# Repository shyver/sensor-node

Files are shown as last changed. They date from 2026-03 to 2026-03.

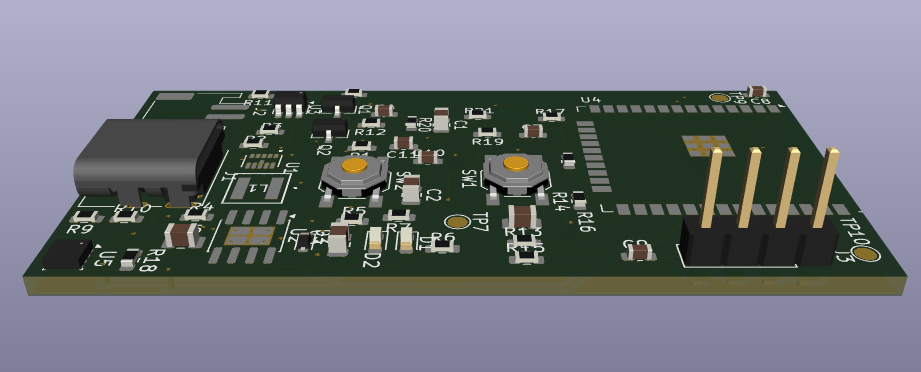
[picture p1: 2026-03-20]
media/pcb_3d_angle.png

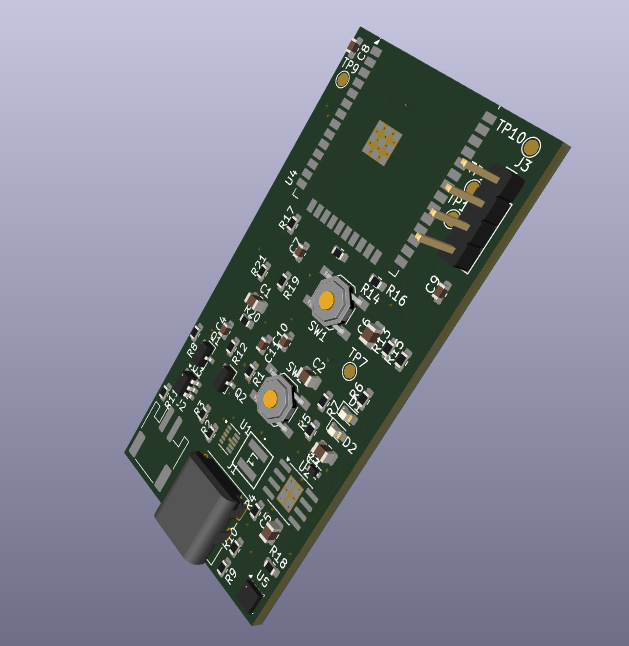
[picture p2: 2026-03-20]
media/pcb_3d_iso.png

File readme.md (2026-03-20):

# Battery-Powered ESP32 Environmental Sensor Node

## Overview

This project is a compact, battery-powered environmental monitoring device built around the ESP32. It is designed to measure temperature, humidity, and atmospheric pressure, and transmit data wirelessly over Wi-Fi.

The system integrates power management, battery charging, sensing, and communication into a single PCB, making it suitable for IoT applications and embedded product prototyping.

---

## Features

* ESP32-based Wi-Fi connectivity
* Environmental sensing (temperature, humidity, pressure)
* Battery-powered operation (Li-Po)
* USB-C power input and charging
* Integrated battery protection
* Low-power design (deep sleep capable)
* UART interface for programming and debugging

---

## Hardware Architecture

The system is composed of the following main subsystems:

### Power Subsystem

* USB-C 5V input
* Li-Po battery charging IC
* Battery protection circuit
* 3.3V regulation stage
* Bulk and decoupling capacitors

### Processing Unit

* ESP32-WROOM-32 module
* Boot configuration and reset circuitry
* UART programming interface

### Sensor Subsystem

* BME280 environmental sensor (I2C interface)
* Pull-up resistors for I2C communication

---

## Block Diagram

```
USB-C → Charger → Battery → Regulator → ESP32 → Sensor (I2C)
```

---

## Design Highlights

* Modular schematic organization (power / MCU / sensor)
* Proper decoupling and power distribution
* ESP32 antenna keep-out respected
* I2C bus design with pull-up resistors
* Battery protection and safe charging design

---

## Key Engineering Decisions

* **ESP32 Module Selection**
  Used a pre-certified ESP32 module to simplify RF design and ensure reliable Wi-Fi performance.

* **Battery-Powered Architecture**
  Designed around a single-cell Li-Po battery for portability and real-world IoT use cases.

* **Power Regulation Strategy**
  Implemented a regulated 3.3V rail to ensure stable operation during ESP32 current spikes.

* **USB-C Power-Only Configuration**
  USB-C connector used strictly for power input, avoiding unnecessary USB data complexity.

* **I2C Sensor Interface**
  Selected a digital sensor with I2C to minimize pin usage and simplify routing.

---

## PCB Design

* 2-layer PCB
* Ground plane for signal integrity
* Compact component placement
* Standard SMD components (0603 passives)
* Connector placement optimized for usability

---

## Files Included

### Design Files

* Schematic files
* PCB layout files

### Manufacturing Files

* Gerbers
* Drill files
* Bill of Materials (BOM)
* Pick-and-place files

### Documentation

* Block diagram
* Rendered board images

---

## Applications

* IoT environmental monitoring
* Smart home systems
* Remote sensing nodes
* Battery-powered embedded systems

---

## Future Improvements

* Power path optimization (load sharing / advanced charger IC)
* Lower power consumption tuning
* OTA firmware update support
* Enclosure design integration
* Additional sensor support

---

## Author

Hardware design and layout by Abdelwahed Eloued

---

## License

This project is open-source and available under the MIT License.

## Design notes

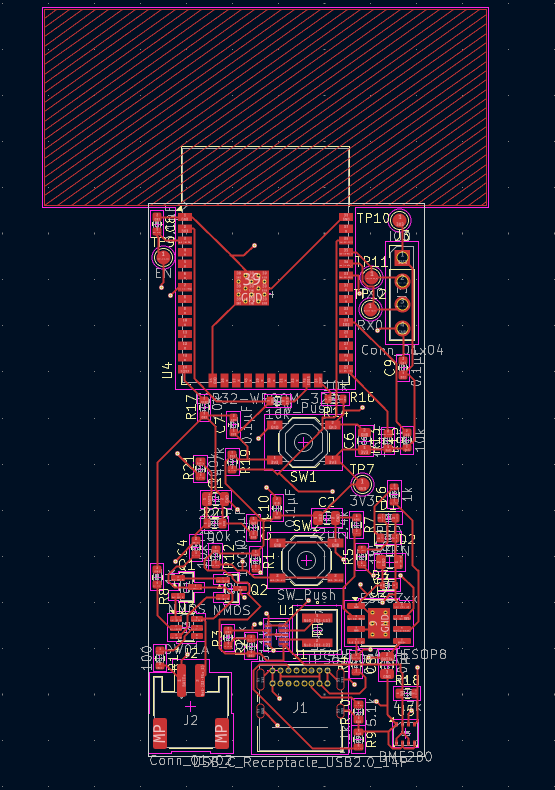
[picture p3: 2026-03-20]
media/pcb_front.png

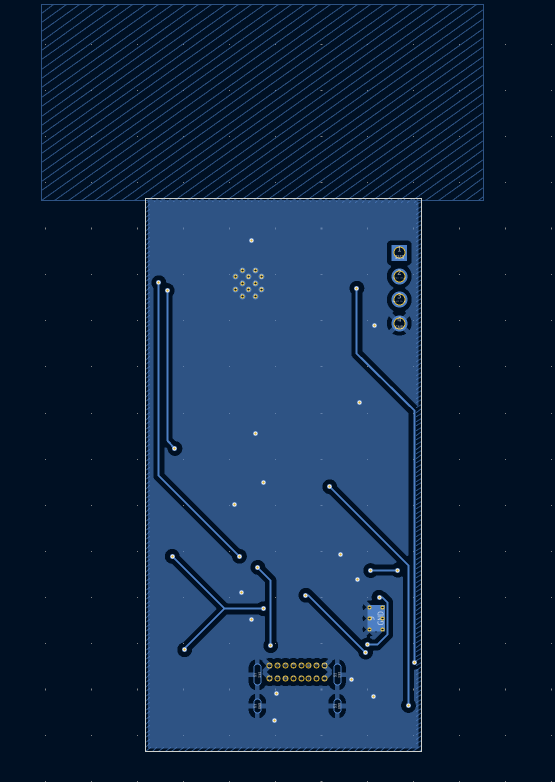
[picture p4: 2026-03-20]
media/pcb_back.png

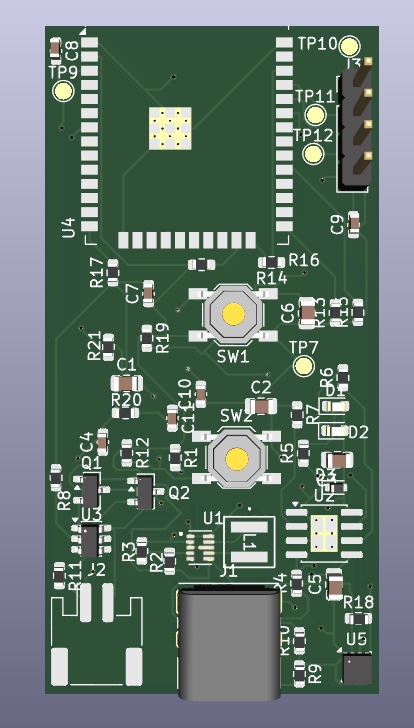
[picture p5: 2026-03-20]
media/pcb_3d_ortho.png

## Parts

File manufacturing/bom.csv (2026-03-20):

Reference | Qty | Value | DNP | Exclude from BOM | Exclude from Board | Footprint | Datasheet
C1,C2 | 2 | 22µF |  |  |  | Capacitor_SMD:C_0805_2012Metric | ~
C3,C5,C6 | 3 | 10µF |  |  |  | Capacitor_SMD:C_0805_2012Metric | ~
C4,C7,C8,C9,C10,C11 | 6 | 0.1µF |  |  |  | Capacitor_SMD:C_0603_1608Metric | ~
D1 | 1 | RED |  |  |  | LED_SMD:LED_0603_1608Metric | ~
D2 | 1 | GREEN |  |  |  | LED_SMD:LED_0603_1608Metric | ~
D3 | 1 | ESD5Zxx |  |  |  | Diode_SMD:D_SOD-523 | https://www.onsemi.com/pdf/datasheet/esd5z2.5t1-d.pdf
J1 | 1 | USB_C_Receptacle_USB2.0_14P |  |  |  | Connector_USB:USB_C_Receptacle_GCT_USB4085 | https://www.usb.org/sites/default/files/documents/usb_type-c.zip
J2 | 1 | Conn_01x02 |  |  |  | Connector_JST:JST_PH_S2B-PH-SM4-TB_1x02-1MP_P2.00mm_Horizontal | ~
J3 | 1 | Conn_01x04 |  |  |  | Connector_PinHeader_2.54mm:PinHeader_1x04_P2.54mm_Vertical | ~
L1 | 1 | 470nH |  |  |  | ul_XFL4015-471MEC:IND_XFL4015_COC-M | ~
Q1,Q2 | 2 | NMOS |  |  |  | Package_TO_SOT_SMD:SOT-23 | https://ngspice.sourceforge.io/docs/ngspice-html-manual/manual.xhtml#cha_MOSFETs
R1,R20,R21 | 3 | 100k |  |  |  | Resistor_SMD:R_0603_1608Metric | ~
R2 | 1 | 511k |  |  |  | Resistor_SMD:R_0603_1608Metric | ~
R3 | 1 | 91k |  |  |  | Resistor_SMD:R_0603_1608Metric | ~
R4 | 1 | 0.4 |  |  |  | Resistor_SMD:R_0603_1608Metric | ~
R5,R6,R8 | 3 | 1k |  |  |  | Resistor_SMD:R_0603_1608Metric | ~
R7 | 1 | 2.4k |  |  |  | Resistor_SMD:R_0603_1608Metric | ~
R9,R10 | 2 | 5.1k |  |  |  | Resistor_SMD:R_0603_1608Metric | ~
R11 | 1 | 100 |  |  |  | Resistor_SMD:R_0603_1608Metric | ~
R12,R13,R14,R15,R16,R17 | 6 | 10k |  |  |  | Resistor_SMD:R_0603_1608Metric | ~
R18,R19 | 2 | 4.7k |  |  |  | Resistor_SMD:R_0603_1608Metric | ~
SW1,SW2 | 2 | SW_Push |  |  |  | Button_Switch_SMD:SW_SPST_TL3342 | ~
TP7 | 1 | 3V3 |  |  |  | TestPoint:TestPoint_Pad_D1.5mm | ~
TP9 | 1 | EN |  |  |  | TestPoint:TestPoint_Pad_D1.5mm | ~
TP10 | 1 | IO0 |  |  |  | TestPoint:TestPoint_Pad_D1.5mm | ~
TP11 | 1 | TX0 |  |  |  | TestPoint:TestPoint_Pad_D1.5mm | ~
TP12 | 1 | RX0 |  |  |  | TestPoint:TestPoint_Pad_D1.5mm | ~
U1 | 1 | TPS63802DLAR |  |  |  | TPS63802DLAR:VREG_TPS63802DLAR
U2 | 1 | TP4056-42-ESOP8 |  |  |  | Package_SO:SOIC-8-1EP_3.9x4.9mm_P1.27mm_EP2.41x3.3mm_ThermalVias | https://www.lcsc.com/datasheet/lcsc_datasheet_2410121619_TOPPOWER-Nanjing-Extension-Microelectronics-TP4056-42-ESOP8_C16581.pdf
U3 | 1 | DW01A |  |  |  | Package_TO_SOT_SMD:SOT-23-6 | https://hmsemi.com/downfile/DW01A.PDF
U4 | 1 | ESP32-WROOM-32E |  |  |  | RF_Module:ESP32-WROOM-32D | https://www.espressif.com/sites/default/files/documentation/esp32-wroom-32e_esp32-wroom-32ue_datasheet_en.pdf
U5 | 1 | BME280 |  |  |  | Package_LGA:Bosch_LGA-8_2.5x2.5mm_P0.65mm_ClockwisePinNumbering | https://www.bosch-sensortec.com/media/boschsensortec/downloads/datasheets/bst-bme280-ds002.pdf

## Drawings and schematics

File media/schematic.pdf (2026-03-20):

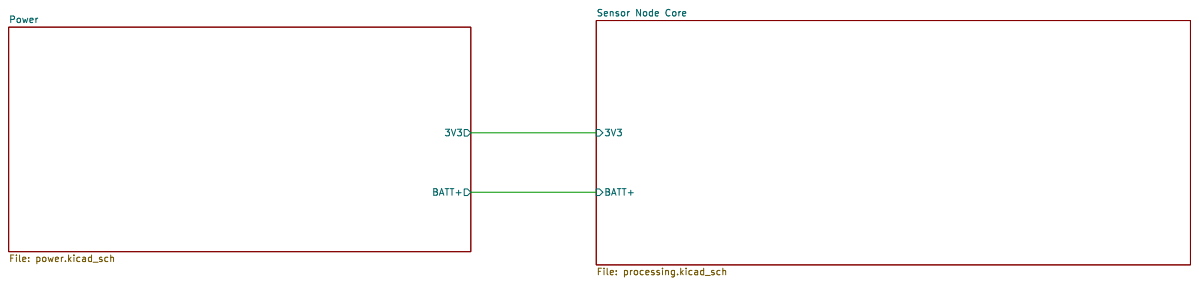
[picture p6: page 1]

3V3 BATT+ Power File: power.kicad_sch

3V3 BATT+ Sensor Node Core File: processing.kicad_sch

Id: 1/3 Title: File: sensor_node_kicad.kicad_sch Sheet: /

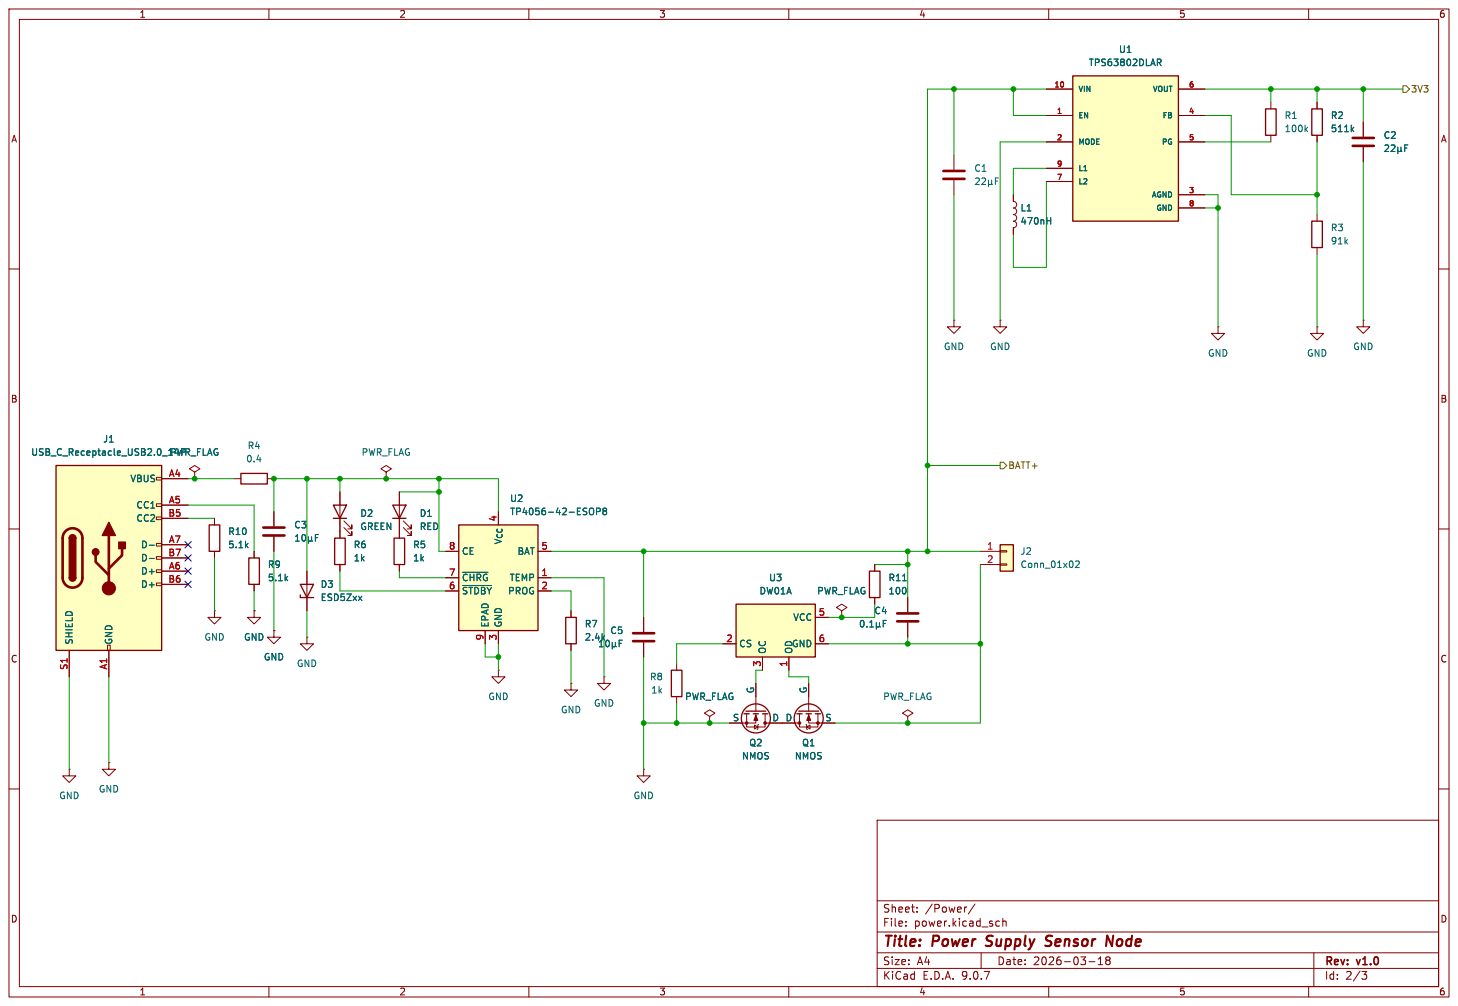
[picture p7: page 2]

3 BAT 5 TEMP 1 PROG 2 U2 TP4056-42-ESOP8 GND

File: power.kicad_sch Sheet: /Power/
Id: 2/3 Title: Power Supply Sensor Node

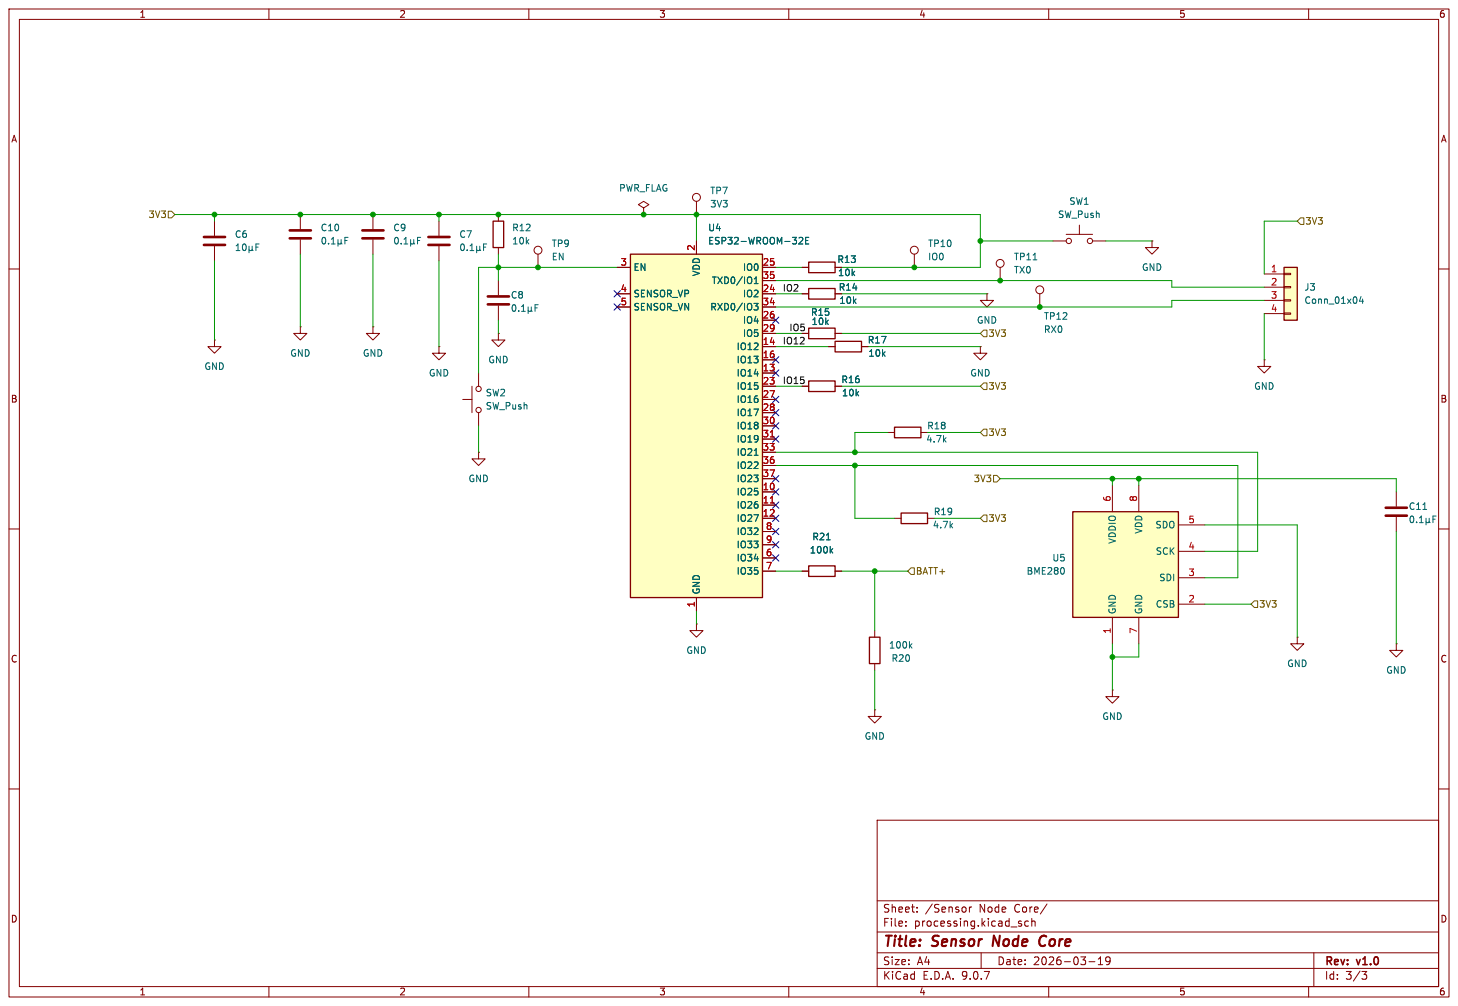
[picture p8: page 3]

7 SDO 5 SCK 4 SDI 3 CSB 2 U5 BME280 C7

Id: 3/3 Title: Sensor Node Core

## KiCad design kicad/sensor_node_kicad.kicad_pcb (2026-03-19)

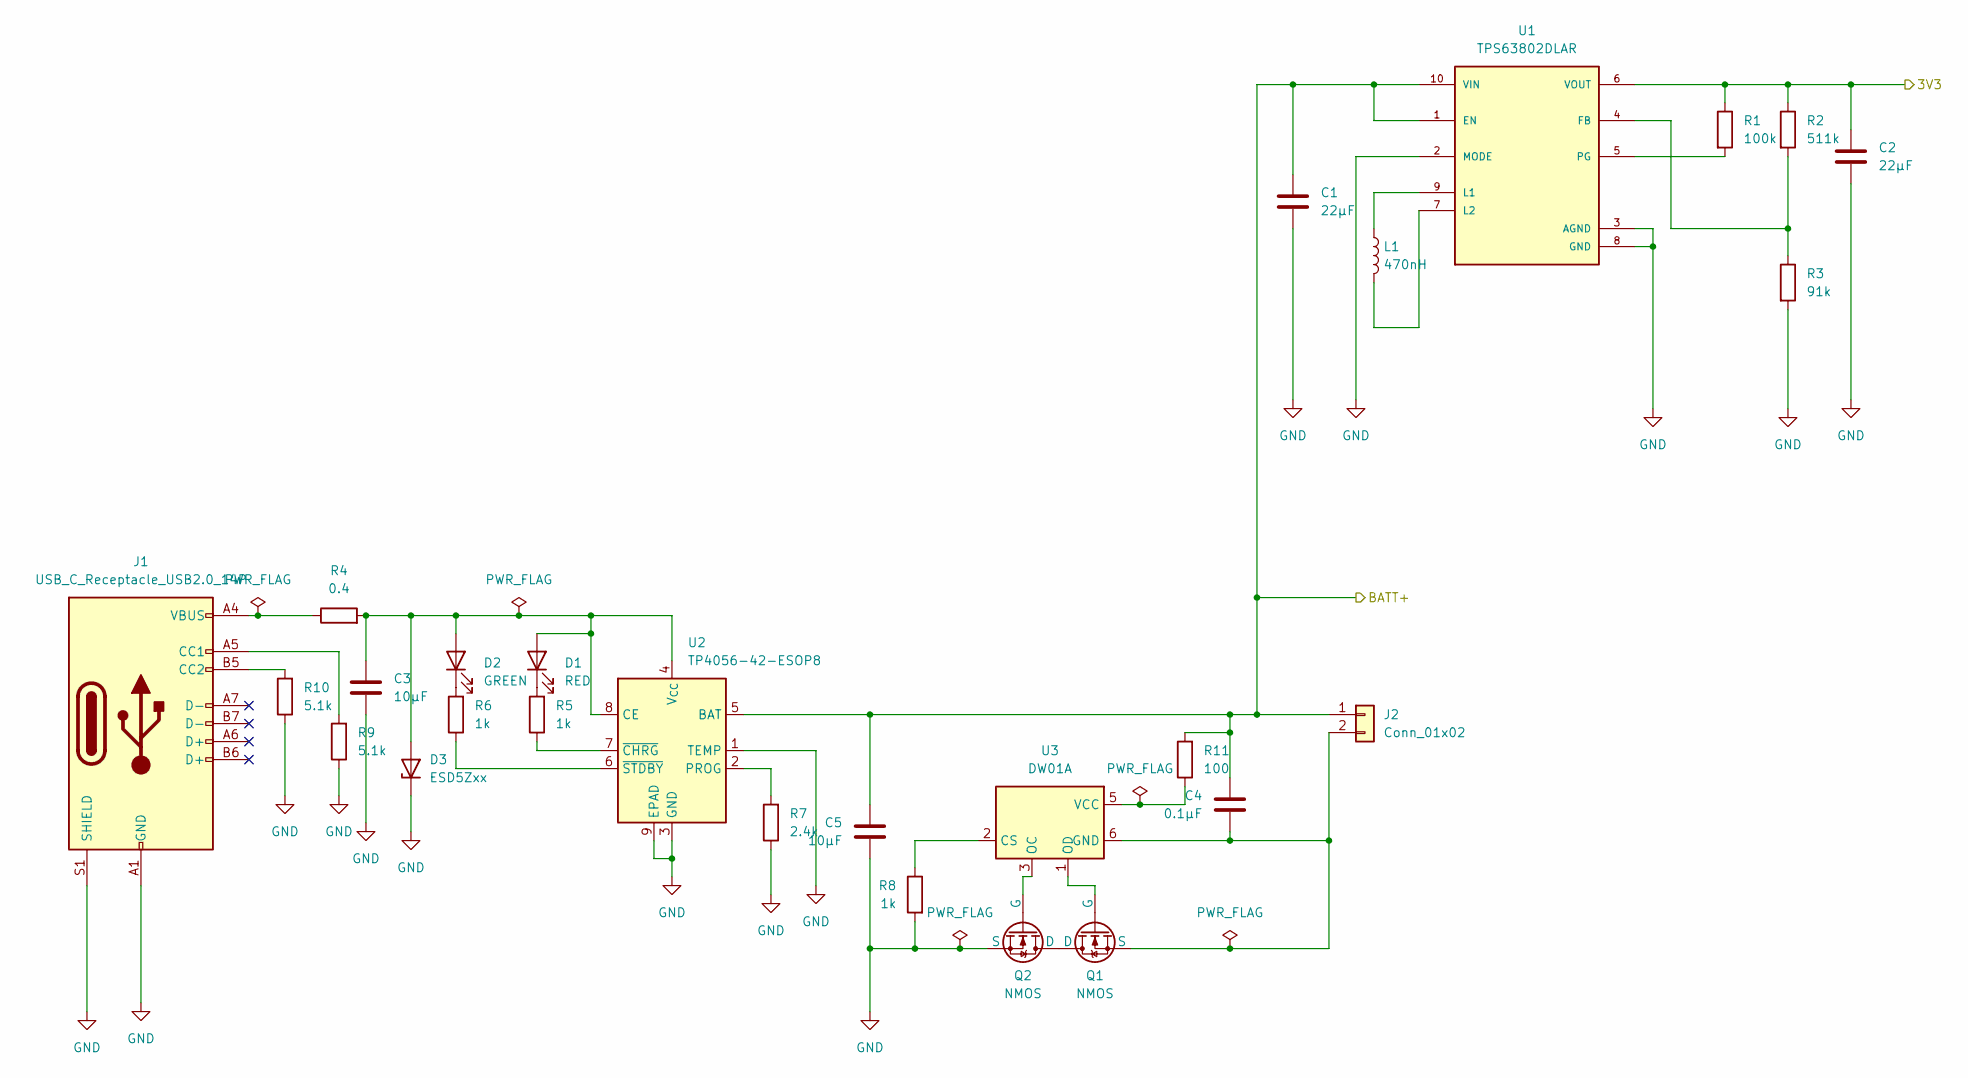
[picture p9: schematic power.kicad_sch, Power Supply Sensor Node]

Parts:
C1, C2: 22µF; C_0805_2012Metric
C3, C5: 10µF; C_0805_2012Metric
C4: 0.1µF; C_0603_1608Metric
D1: RED; LED_0603_1608Metric
D2: GREEN; LED_0603_1608Metric
D3: ESD5Zxx; D_SOD-523
J1: USB_C_Receptacle_USB2.0_14P; USB_C_Receptacle_GCT_USB4085
J2: Conn_01x02; JST_PH_S2B-PH-SM4-TB_1x02-1MP_P2.00mm_Horizontal
L1: 470nH; IND_XFL4015_COC-M
Q1, Q2: NMOS; SOT-23
R1: 100k; R_0603_1608Metric
R2: 511k; R_0603_1608Metric
R3: 91k; R_0603_1608Metric
R4: 0.4; R_0603_1608Metric
R5, R6, R8: 1k; R_0603_1608Metric
R7: 2.4k; R_0603_1608Metric
R9, R10: 5.1k; R_0603_1608Metric
R11: 100; R_0603_1608Metric
U1: TPS63802DLAR; VREG_TPS63802DLAR; PARTREV B
U2: TP4056-42-ESOP8; SOIC-8-1EP_3.9x4.9mm_P1.27mm_EP2.41x3.3mm_ThermalVias
U3: DW01A; SOT-23-6

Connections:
/Power/3V3: C2.1, R1.1, R2.1, U1.6 (VOUT); also elsewhere on the board
/Power/BATT+: C1.1, C4.2, C5.2, J2.1, R11.2, U1.1 (EN), U1.10 (VIN), U2.5 (BAT); also elsewhere on the board
GND: C1.2, C2.2, C3.2, C5.1, D3.1 (K), J1.A1 (GND), J1.A12 (GND), J1.B1 (GND), J1.B12 (GND), J1.S1 (SHIELD), Q2.3 (S), R3.2, R7.1, R8.2, R9.1, R10.1, U1.2 (MODE), U1.3 (AGND), U1.8 (GND), U2.1 (TEMP), U2.3 (GND), U2.9 (EPAD); also elsewhere on the board
unnamed: C3.1, D1.2 (A), D2.2 (A), D3.2 (A), R4.2, U2.4 (V_{CC}), U2.8 (CE)
unnamed: D1.1 (K), R5.2
unnamed: D2.1 (K), R6.2
unnamed: J1.A5 (CC1), R9.2
unnamed: J1.B5 (CC2), R10.2
unnamed: J1.A4 (VBUS), J1.A9 (VBUS), J1.B4 (VBUS), J1.B9 (VBUS), R4.1
unnamed: C4.1, J2.2, Q1.3 (S), U3.6 (GND)
unnamed: Q1.1 (D), Q2.1 (D)
unnamed: Q1.2 (G), U3.1 (OD)
unnamed: Q2.2 (G), U3.3 (OC)
unnamed: R2.2, R3.1, U1.4 (FB)
unnamed: L1.1, U1.9 (L1)
unnamed: L1.2, U1.7 (L2)
unnamed: R1.2, U1.5 (PG)
unnamed: R7.2, U2.2 (PROG)
unnamed: R5.1, U2.7 (~CHRG)
unnamed: R6.1, U2.6 (~STDBY)
unnamed: R8.1, U3.2 (CS)
unnamed: R11.1, U3.5 (VCC)

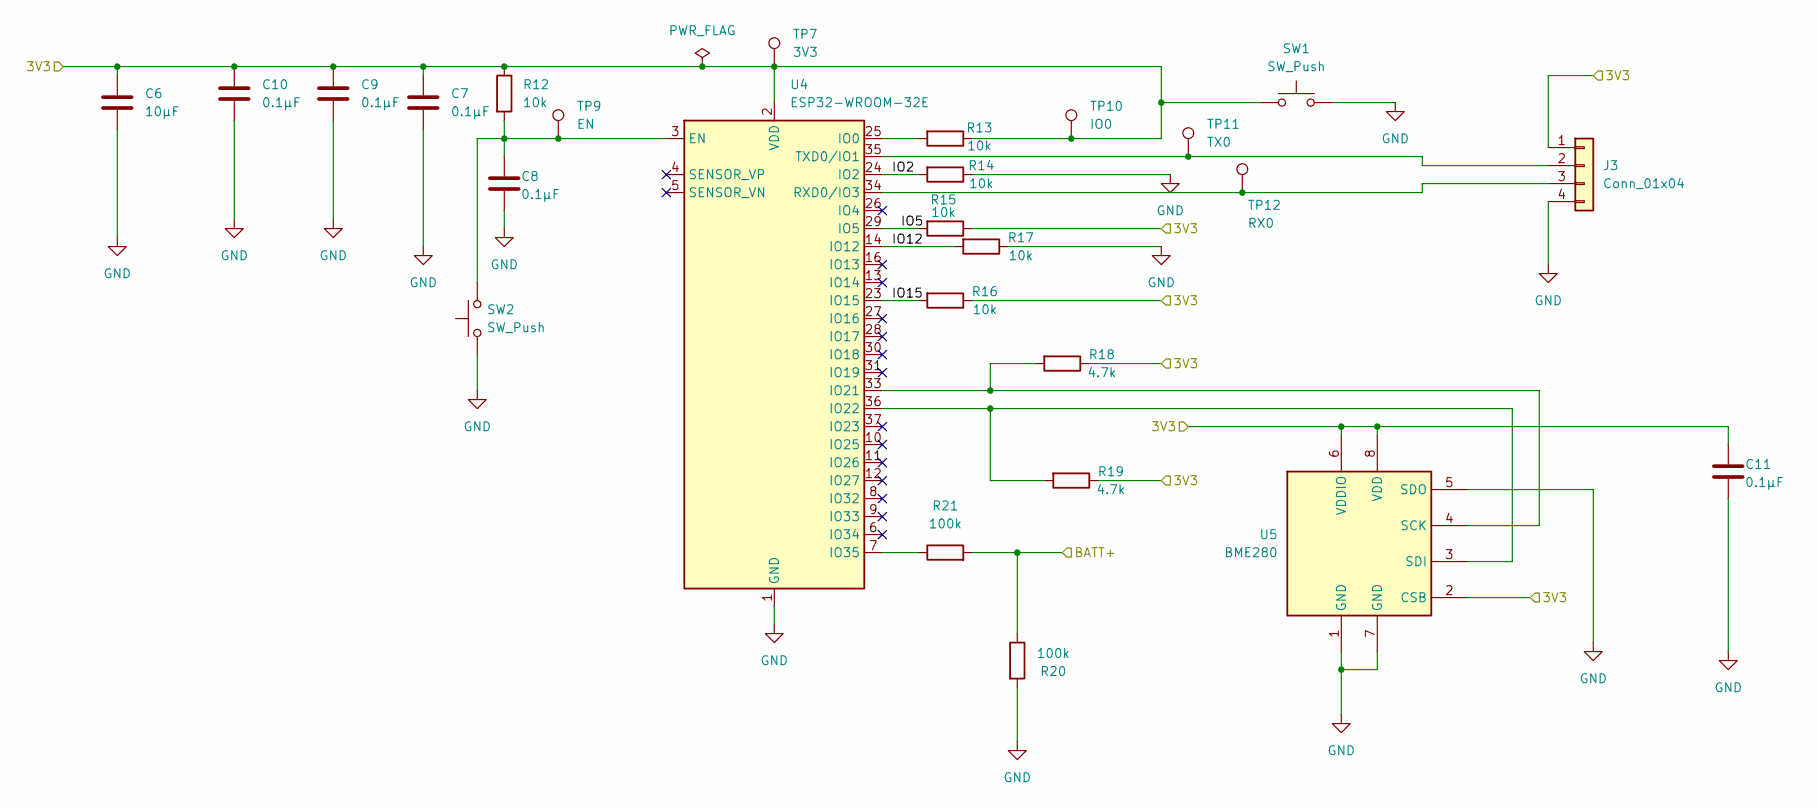
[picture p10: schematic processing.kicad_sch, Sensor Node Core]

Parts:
C6: 10µF; C_0805_2012Metric
C7, C8, C9, C10, C11: 0.1µF; C_0603_1608Metric
J3: Conn_01x04; PinHeader_1x04_P2.54mm_Vertical
R12, R13, R14, R15, R16, R17: 10k; R_0603_1608Metric
R18, R19: 4.7k; R_0603_1608Metric
R20, R21: 100k; R_0603_1608Metric
SW1, SW2: SW_Push; SW_SPST_TL3342
TP7: 3V3; TestPoint_Pad_D1.5mm
TP9: EN; TestPoint_Pad_D1.5mm
TP10: IO0; TestPoint_Pad_D1.5mm
TP11: TX0; TestPoint_Pad_D1.5mm
TP12: RX0; TestPoint_Pad_D1.5mm
U4: ESP32-WROOM-32E; ESP32-WROOM-32D
U5: BME280; Bosch_LGA-8_2.5x2.5mm_P0.65mm_ClockwisePinNumbering

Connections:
/Power/3V3: C6.1, C7.1, C9.1, C10.1, C11.1, J3.1, R12.1, R13.1, R15.1, R16.1, R18.1, R19.1, SW1.1, TP7.1, TP10.1, U4.2 (VDD), U5.2 (CSB), U5.6 (VDDIO), U5.8 (VDD); also elsewhere on the board
/Power/BATT+: R20.1, R21.2; also elsewhere on the board
/Sensor Node Core/IO2: R14.2, U4.24 (IO2)
/Sensor Node Core/IO5: R15.2, U4.29 (IO5)
/Sensor Node Core/IO12: R17.2, U4.14 (IO12)
/Sensor Node Core/IO15: R16.2, U4.23 (IO15)
GND: C6.2, C7.2, C8.2, C9.2, C10.2, C11.2, J3.4, R14.1, R17.1, R20.2, SW1.2, SW2.1, U4.1 (GND), U4.15 (GND), U4.38 (GND), U4.39 (GND), U5.1 (GND), U5.5 (SDO), U5.7 (GND); also elsewhere on the board
unnamed: J3.2, TP11.1, U4.35 (TXD0/IO1)
unnamed: J3.3, TP12.1, U4.34 (RXD0/IO3)
unnamed: C8.1, R12.2, SW2.2, TP9.1, U4.3 (EN)
unnamed: R13.2, U4.25 (IO0)
unnamed: R18.2, U4.33 (IO21), U5.4 (SCK)
unnamed: R19.2, U4.36 (IO22), U5.3 (SDI)
unnamed: R21.1, U4.7 (IO35)

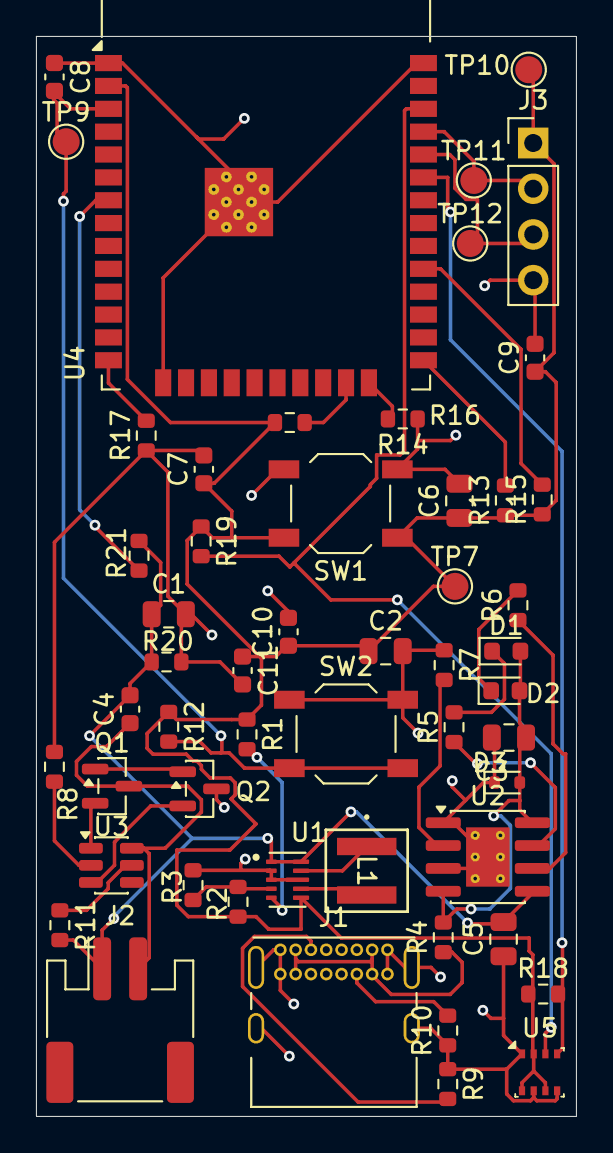
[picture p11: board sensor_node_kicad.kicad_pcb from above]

Board: 2 copper layers, 30.0 x 60.0 mm, 53 parts (0 on the bottom side), 33 nets.

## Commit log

2026-03-19 progressed in the processing unit, BME280 still needs proper implementation
    [processing.kicad_sch, sensor_node_kicad.kicad_sch]
2026-03-19 completed the sensor node core (esp32 and the sensor chip)
    [processing.kicad_sch]
2026-03-19 finalized the schematic design
    [power.kicad_sch, processing.kicad_sch, sensor_node_kicad.kicad_sch]
2026-03-19 finalized layout
    [sensor_node_kicad.kicad_pcb]
2026-03-19 added metadata
    [sensor_node_kicad.kicad_pcb]
2026-03-20 added manufacturing files
    [bom.csv, power.kicad_sch, processing.kicad_sch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]
2026-03-20 added schematic pdf
